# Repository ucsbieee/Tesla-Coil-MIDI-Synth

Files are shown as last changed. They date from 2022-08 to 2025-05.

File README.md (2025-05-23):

# UCSB IEEE Tesla Coil MIDI Synthesizer

This is the firmware and design files for a device to convert MIDI data to pulses to drive a Tesla coil. It enumerates as a USB MIDI device and can be sent live play data or a recorded MIDI file. It also enumerates as a USB audio device and can be sent PCM audio for greater control or for live instrument use.

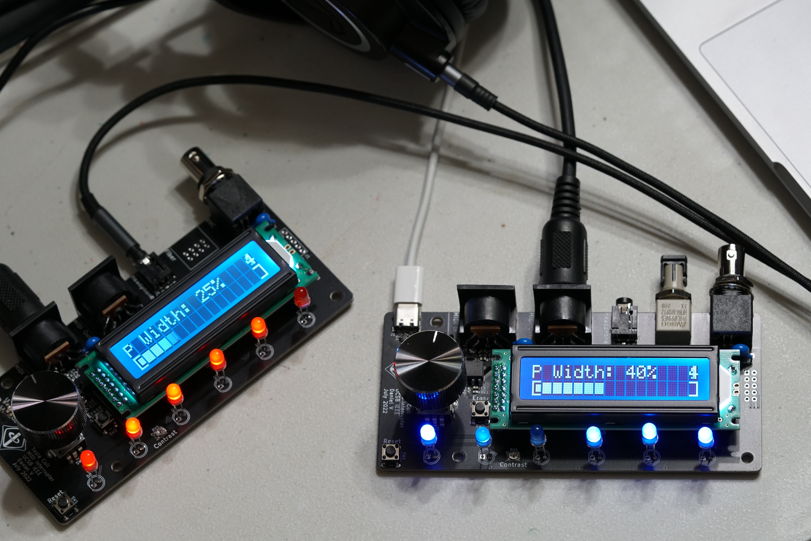
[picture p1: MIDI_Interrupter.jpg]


The circuit board is based off of the [Arduino Due](https://docs.arduino.cc/hardware/due). It uses the similar SAM3A4C MCU, and has a fiber optic output for the big DRSSTC and a BNC port for the small Tesla Coil. It also has isolated physical MIDI in/out ports for connecting other instruments or daisy-chaining more MIDI interrupters. See [ucsbieee/ArduinoCore-SAM3A4C](https://github.com/ucsbieee/ArduinoCore-SAM3A4C) for an Arduino IDE board definition.

The device has six voices, which can each produce a single square wave tone at a variable duty cycle. They are ORed together to give a polyphonic effect.

## Uploading Firmware

New firmware can be uploaded using the Arduino IDE and the aforementioned [board definition](https://github.com/ucsbieee/ArduinoCore-SAM3A4C), or the [latest release](https://github.com/ucsbieee/Tesla-Coil-MIDI-Synth/releases/latest) (`.bin` file) can be uploaded using [BOSSA](https://github.com/shumatech/BOSSA) ([available from Homebrew](https://formulae.brew.sh/formula/bossa)).

### Arduino Library Dependencies
Available from the Arduino IDE library manager
 * [MIDIUSB](https://github.com/arduino-libraries/MIDIUSB)
 * [DueFlashStorage](https://github.com/sebnil/DueFlashStorage) (only if `SAVE_BASE_MIDI` is enabled, which it is not by default)

## Emulator

There is also an emulator that can be compiled to run on a normal computer so that songs can be developed without the physical hardware.

## MIDI Information

### MIDI Channels
 1. Clean (no effects)
 2. Effects
 3. Arpeggio and effects
 4. Drums

Standard MIDI pitch bend and aftertouch messages apply to all channels.

### Effects (CC number in parentheses)
 * Tremolo (rate = 102, depth = 92, delay = 103)
 * Vibrato (rate = 76, depth = 77, delay = 78)
 * ADSR (116, 117, 118, 119)
 * Arpeggio rate (14)

### Drum Samples
 * Kick (36/C2)
 * Snare (40/E2)
 * Clap (39/D#2)
 * Tom (48/C3)
 * Closed hi-hat (42/F#2)

### Physical MIDI Ports
All MIDI messages that come in over USB or the MIDI IN port are sent out the MIDI OUT port. Additionally, all messages that come in over the MIDI IN port are sent back to the computer over USB. This allows daisy-chaining multiple controllers using the physical MIDI ports, and allows recording any inputs from the physical MIDI IN port to the computer. Be careful not to create infinite MIDI loops in your DAW because of these behaviors.

## Audio Processing Modes
 * **Predictive**: Predict how much energy will be in a pulse based on the filtered derivative near zero crossing.
 * **Pulse Energy**: Output a pulse after a delay (~5ms) with width proportional to the area of the input pulse above the noise gate level. Pulse width clamped to maximum setting.
 * **Schmitt**: Output on when audio exceeds the noise gate level, then only turn off again once audio falls below negative noise gate level (Schmitt trigger behavior). Pulse width clamped to maximum setting.
 * **Clamped Binary**: Output on when audio exceeds the noise gate level. Pulse width clamped to maximum setting.
 * **Binary**: Output on when audio exceeds the noise gate level.
 * **Binary DDT**: Output on when the derivative of the audio exceeds a certain threshold. Pulse width clamped to maximum setting.
 * **Bin Oct Down**: Toggle output on rising edge. Input schmitt triggered. Output pulse width limited.
 * **PWM**: Output 48kHz PWM with pulse width proportional to the sample value. Audio baseline level subtracted away.
 * **PWM DDT**: Output 48kHz PWM with pulse width proportional to the derivative of the audio.

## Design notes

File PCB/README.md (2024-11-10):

# PCB

## Audio

We had the idea of using sampled audio output after the V2 boards were made. Unfortunately, the (unused) pins that have the necessary DMA capability are not broken out on the board. So, to get audio capability, you will need to solder a very thin wire (~34AWG) underneath the D10 pad on the microcontroller and run it to EXT_IN on the expansion header. Hope you're comfortable with BGA soldering :)

## Hacking
There are twelve extra pins on the board marked "Expansion," and they're there so you can add extra inputs or whatever you want to the board. Three are power (5V, 3.3V, GND), and seven go to digital/ADC pins on the MCU. The Arduino board definition is based off of the DUE, so take a look at the [DUE schematic](https://www.arduino.cc/en/uploads/Main/arduino-Due-schematic.pdf) or [variant.cpp](https://github.com/ucsbieee/ArduinoCore-SAM3A4C/blob/master/variants/arduino_due_x/variant.cpp) to see which Arduino pins they map to. These could be good for adding physical controls/music input of some kind.

There's also an input that is ORed with the voice signals before being sent to the outputs, and a 3.3V logic level copy of that combined output signal available. You can use these to make use of the output circuitry to control the Tesla coil with your own signals, combine voices from multiple interrupter boards (chaos), or whatever else you can think of.

## Erase and Reset Buttons
Pressing the "Erase" button on the PCB immediately deletes the firmware. Don't push it unless you intend to. This microcontroller has the SAM-BA bootloader included in ROM which is activated when the chip is blank, causing it to enumerate as a USB serial device and accept new firmware. If you ever get the board into a state where you can't program it, hit the erase button then reset and that should fix it. After uploading new firmware to a blank chip, you may need to re-power (instead of reset) the board. If it wasn't blank, you usually can just hit the reset button to make it run the new firmware.

If you accidentally nuked the chip, there's a firmware binary file in this repo and you can upload it using [bossa](https://github.com/shumatech/BOSSA/releases).

## If you want to make more

There should be a few extra unpopulated boards in the lab somewhere. See [BOM.csv](https://github.com/ucsbieee/Tesla-Coil-MIDI-Synth/blob/master/PCB/BOM.csv) for a list of parts you'll need. Parts without a DigiKey part number are generic stuff. Most resistors and caps are 0603, with a few 0805 (see footprint column).

You'll also likely want to use a solder paste stencil, especially for the BGA microcontroller. A file for the stencil is in the Gerber folder.

If you guys ever build a Tesla Coil symphony with a bunch of these things, please invite me back, I want to see :)

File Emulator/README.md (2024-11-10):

# Emulated MIDI Synth

This folder contains code to patch/modify the software that runs on the microcontroller on the Tesla coil controller box so that it can run on a normal computer. There is also some glue code that uses [PortAudio](https://github.com/PortAudio/portaudio) and [libremidi](https://github.com/jcelerier/libremidi) to enable MIDI input and sound output. This allows songs to be more easily developed without needing a physical controller box plugged in (especially if you want to use the CC-controlled effects channels).

## Building

Prerequisites
 * [`portaudiocpp`](https://github.com/PortAudio/portaudio)
 * [`fftw`](https://www.fftw.org)
 * [`libremidi`](https://github.com/jcelerier/libremidi)
 * [`SDL2`](https://www.libsdl.org) (and `SDL2_ttf`)
 * GNU `make`
 * `patch`
 * C++17 compiler

You may need to modify the makefile slightly to get it to find the libraries on your system (it uses `pkg-config` by default) or to select a different backend for `libremidi` depending on your operating system.

Running `make` will take the code from the main firmware in this repo and apply some patches to remove MCU-specific code.

## Using

When the program is run, it will ask you for audio input and output devices and a MIDI input device. Set the audio input device to a guitar or loopback source, output device to your headphones, and the MIDI input to a loopback device coming out of your DAW. It should respond exactly like the real MIDI controller since it's the exact same code. The sound is approximated using an FIR filter.

If run with the `--stereo` flag, the program will emulate two Tesla coil controllers, one panned to the left and the other to the right. The right one responds to MIDI channels starting at 5 instead of 1.

Use the arrow keys and return/space or mouse wheel and click to navigate the settings.

## Modifying

Significant modifications to the MCU firmware may require the patches to be re-done. Changes to files can be propagated back to the `.patch` files by running `make patches` after modifying the files produced by running `make build/patched/x.cpp`.

## Attribution

LCD font from [here](https://fontstruct.com/fontstructions/show/476121/lcd_dot_matrix_hd44780u).

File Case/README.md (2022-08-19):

# Case
* [Case screws](https://www.mcmaster.com/94629A680/)
* [MIDI port screws](https://www.mcmaster.com/90380A005/)

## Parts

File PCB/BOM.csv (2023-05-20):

Item | Qty | Reference(s) | Value | LibPart | Footprint | Datasheet | DigiKey Part Number
1 | 5 | C1, C5, C10, C17, C24 | 10µ | Device:C_Small | Capacitor_SMD:C_0805_2012Metric_Pad1.18x1.45mm_HandSolder
2 | 16 | C2, C3, C4, C6, C7, C8, C11, C14, C15, C16, C18, C20, C21, C22, C25, C26 | 100n | Device:C_Small | Capacitor_SMD:C_0603_1608Metric_Pad1.08x0.95mm_HandSolder
3 | 3 | C9, C12, C13 | 10p | Device:C_Small | Capacitor_SMD:C_0603_1608Metric_Pad1.08x0.95mm_HandSolder
4 | 2 | C19, C23 | 1n | Device:C_Small | Capacitor_THT:C_Disc_D7.5mm_W5.0mm_P7.50mm
5 | 1 | D1 | D1213 | Custom_Symbols:D1213 | Custom_Footprints:SOT25 | https://www.diodes.com/assets/Datasheets/D1213A-02SM.pdf | D1213A-02SM-7DICT-ND
6 | 1 | D2 | Voice 1 | Device:LED | LED_THT:LED_D5.0mm
7 | 1 | D3 | Voice 2 | Device:LED | LED_THT:LED_D5.0mm
8 | 1 | D4 | Voice 3 | Device:LED | LED_THT:LED_D5.0mm
9 | 1 | D5 | Voice 4 | Device:LED | LED_THT:LED_D5.0mm
10 | 1 | D6 | Voice 5 | Device:LED | LED_THT:LED_D5.0mm
11 | 1 | D7 | Voice 6 | Device:LED | LED_THT:LED_D5.0mm
12 | 1 | D8 | D | Device:D | Diode_SMD:D_SOD-123 |  | 1727-7320-1-ND
13 | 6 | FB1, FB2, FB3, FB4, FB5, FB6 | FerriteBead_Small | Device:FerriteBead_Small | Inductor_SMD:L_0805_2012Metric_Pad1.05x1.20mm_HandSolder |  | 1276-6377-1-ND
14 | 1 | FL1 | Filter_EMI_CommonMode | Device:Filter_EMI_CommonMode | Custom_Footprints:Bourns_SRF2012AA |  | SRF2012A-900YACT-ND
15 | 1 | J1 | USB C | Connector:USB_C_Receptacle_USB2.0 | Custom_Footprints:GCT_USBC_USB4105 |  | 2073-USB4105-GF-ACT-ND
16 | 1 | J2 | JTAG | Connector_Generic:Conn_02x05_Odd_Even | Connector_PinHeader_1.27mm:PinHeader_2x05_P1.27mm_Vertical
17 | 1 | J3 | Expansion | Connector_Generic:Conn_02x05_Odd_Even | Connector_PinHeader_2.54mm:PinHeader_2x05_P2.54mm_Vertical
18 | 1 | J4 | Headphone Output | Connector:AudioJack3_SwitchTR | Custom_Footprints:Adam_Tech_ASJ-99H-X-HT-TR |  | 2057-ASJ-99H-R-HT-T/RCT-ND
19 | 1 | J5 | BNC Output | Connector:Conn_Coaxial | Custom_Footprints:Adam_Tech_BNC_RF1-01K-D-00-50-BK-HDW |  | 2057-RF1-01K-D-00-50-BK-HDW-ND, SC2808-ND
20 | 1 | J6 | MIDI Out | Connector:DIN-5_180degree | Custom_Footprints:CUI_DIN_SDS-50J |  | CP-2350-ND
21 | 1 | J7 | MIDI In | Connector:DIN-5_180degree | Custom_Footprints:CUI_DIN_SDS-50J |  | CP-2350-ND
22 | 1 | L1 | 4.7µ | Device:L | Inductor_SMD:L_0805_2012Metric_Pad1.05x1.20mm_HandSolder |  | 445-8659-1-ND
23 | 10 | R1, R2, R4, R7, R8, R9, R17, R20, R22, R27 | 10k | Device:R_US | Resistor_SMD:R_0603_1608Metric_Pad0.98x0.95mm_HandSolder
24 | 1 | R3 | 6.8k | Device:R_US | Resistor_SMD:R_0603_1608Metric_Pad0.98x0.95mm_HandSolder
25 | 2 | R5, R6 | 39 | Device:R_US | Resistor_SMD:R_0603_1608Metric_Pad0.98x0.95mm_HandSolder
26 | 11 | R10, R11, R12, R13, R14, R15, R21, R23, R24, R25, R26 | 220 | Device:R_US | Resistor_SMD:R_0603_1608Metric_Pad0.98x0.95mm_HandSolder
27 | 2 | R16, R28 | 5.1k | Device:R_US | Resistor_SMD:R_0603_1608Metric_Pad0.98x0.95mm_HandSolder
28 | 2 | R18, R19 | 100 | Device:R_US | Resistor_SMD:R_0603_1608Metric_Pad0.98x0.95mm_HandSolder
29 | 1 | R29 | 3.3 | Device:R_US | Resistor_SMD:R_0603_1608Metric_Pad0.98x0.95mm_HandSolder
30 | 1 | RV1 | Contrast | Device:R_Potentiometer_Trim_US | Potentiometer_SMD:Potentiometer_Bourns_TC33X_Vertical |  | TC33X-103ECT-ND
31 | 2 | SG1, SG2 | SparkGap | Device:SparkGap | Custom_Footprints:Spark_Gap
32 | 1 | SW1 | Reset | Switch:SW_Push | Button_Switch_THT:SW_PUSH_6mm
33 | 1 | SW2 | Erase | Switch:SW_Push | Button_Switch_THT:SW_PUSH_6mm
34 | 1 | SW3 | Rotary Encoder | Device:RotaryEncoder_Switch | Custom_Footprints:Bourns_Encoder_PEC12R-4130F-S0012 |  | PEC12R-4130F-S0012-ND, 1568-1601-ND
35 | 1 | U1 | AZ1117-3.3 | Regulator_Linear:AZ1117-3.3 | Package_TO_SOT_SMD:SOT-89-3 |  | AZ1117CR-3.3TRG1DICT-ND
36 | 1 | U2 | SAM3A4C | Custom_Symbols:SAM3A4C | Package_BGA:TFBGA-100_9.0x9.0mm_Layout10x10_P0.8mm | http://www.microchip.com/mymicrochip/filehandler.aspx?ddocname=en590017 | 1611-ATSAM3A4CA-CU-ND
37 | 1 | U3 | SFH617A-1 | Isolator:SFH617A-1 | Package_DIP:DIP-4_W10.16mm |  | 732-140817141310-ND
38 | 1 | U4 | HFBR-1412PTZ | Custom_Symbols:HFBR-1412PTZ | Custom_Footprints:Broadcom_HFBR-1412PTZ | https://docs.broadcom.com/doc/AV02-0176EN | 516-4074-ND
39 | 1 | U5 | 74LVC4245A | Custom_Symbols:74LVC4245A | Package_SO:TSSOP-24_4.4x7.8mm_P0.65mm | https://assets.nexperia.com/documents/data-sheet/74LVC4245A.pdf | 1727-4308-1-ND
40 | 1 | U6 | 6N137 | Isolator:6N137 | Package_DIP:DIP-8_W7.62mm |  | 160-1791-ND
41 | 1 | U7 | ERM1602 | Custom_Symbols:ERM1602 | Custom_Footprints:ERM1602 | https://www.buydisplay.com/download/manual/ERM1602-2.1_Series_Datasheet.pdf
42 | 1 | U8 | 4075 | 4xxx:4075 | Package_SO:SOIC-14_3.9x8.7mm_P1.27mm |  | 296-SN74HCS4075DRCT-ND
43 | 1 | U9 | 74LVC1G17 | 74xGxx:74LVC1G17 | Package_TO_SOT_SMD:SOT-23-5 |  | 296-11933-1-ND
44 | 1 | Y1 | 12MHz | Device:Crystal_GND24 | Crystal:Crystal_SMD_Abracon_ABM8G-4Pin_3.2x2.5mm |  | 535-10901-1-ND

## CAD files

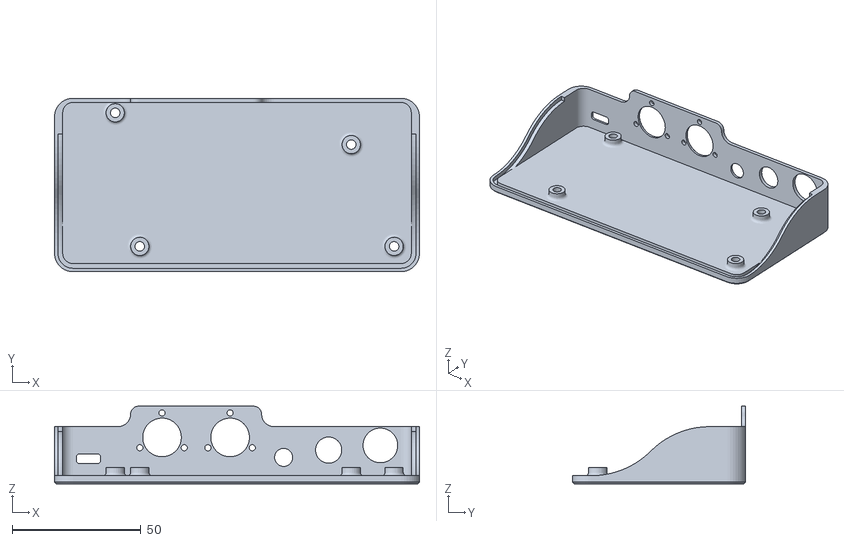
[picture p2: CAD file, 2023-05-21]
Case/Bottom.stl
141.6 x 67.3 x 30.2

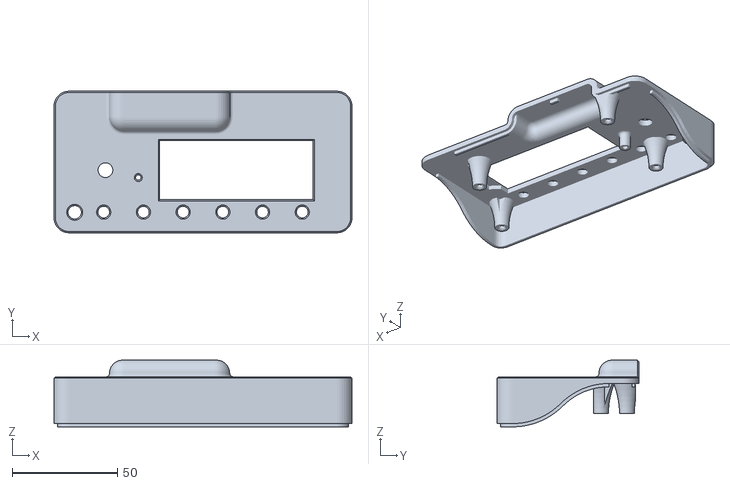
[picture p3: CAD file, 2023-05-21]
Case/Top.stl
141.6 x 67.3 x 31.8

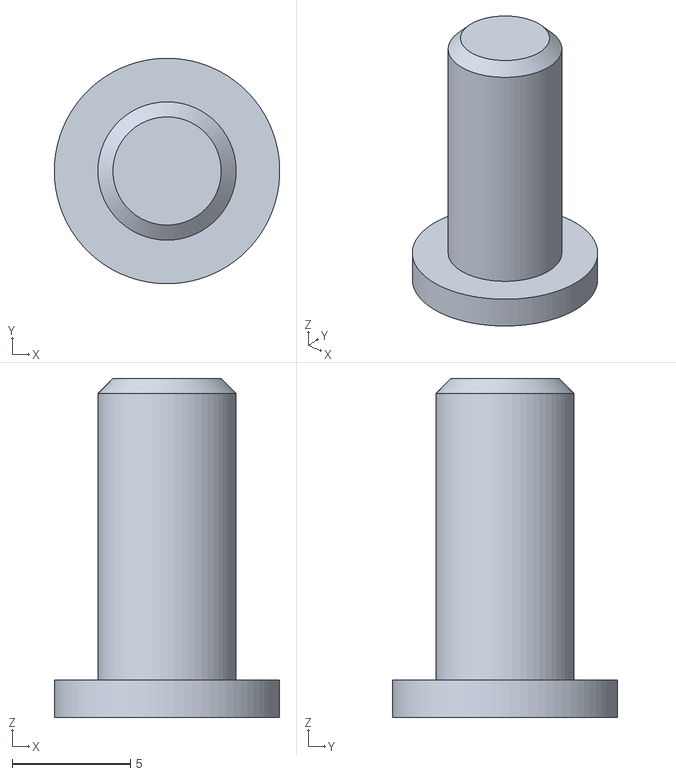
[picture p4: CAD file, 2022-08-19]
Case/Button Pusher.stl
9.52 x 9.52 x 14.3

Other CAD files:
Case/Bottom No Fiber Optic.stl

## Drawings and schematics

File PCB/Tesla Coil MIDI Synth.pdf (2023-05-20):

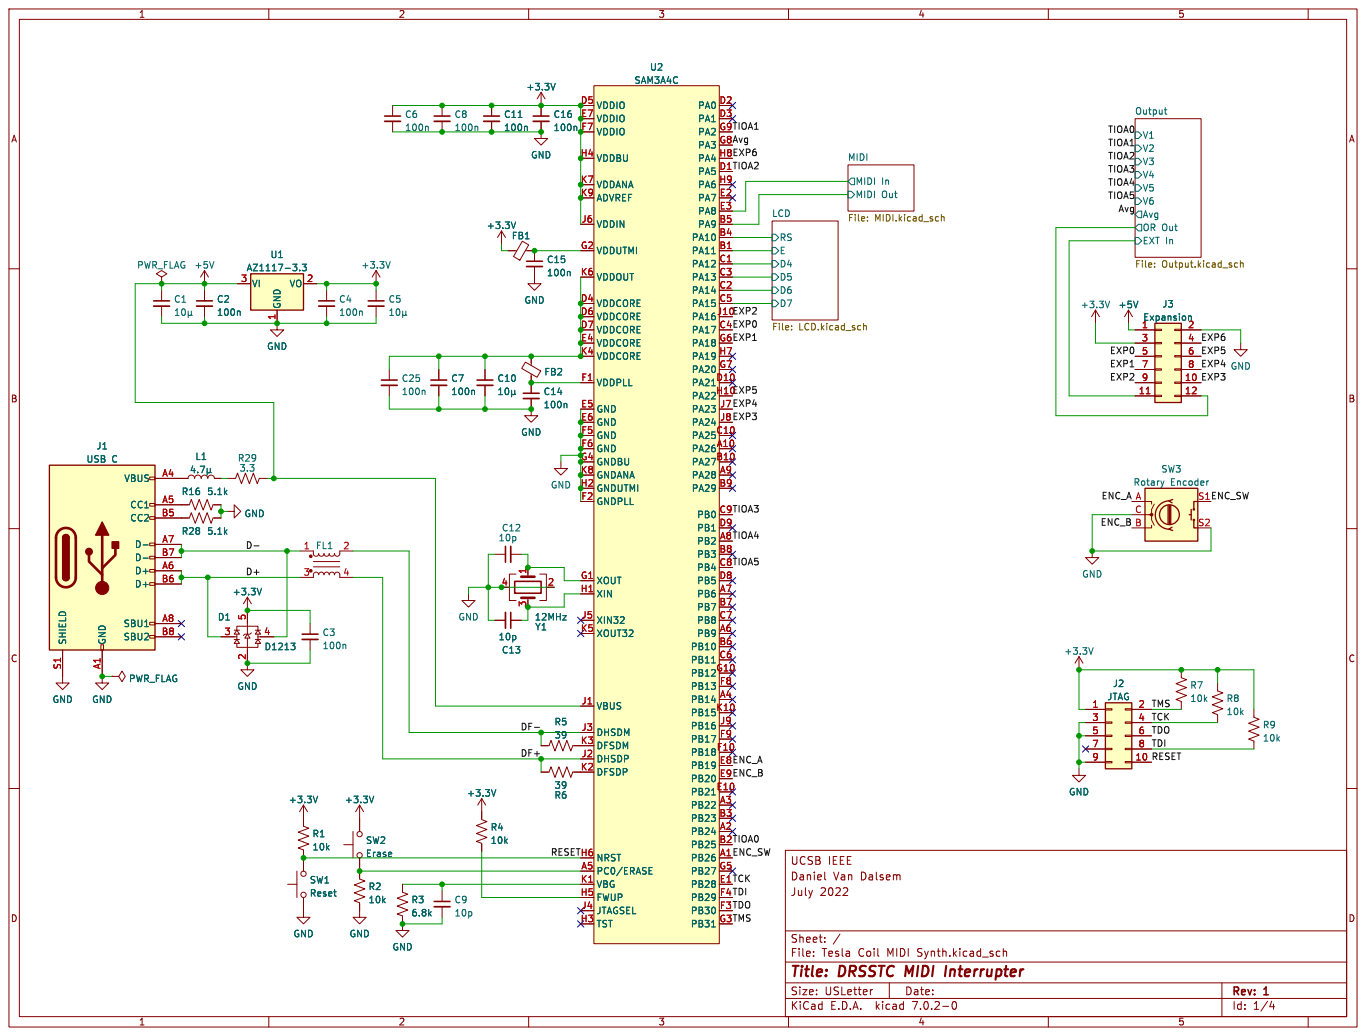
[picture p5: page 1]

PA7 E2 PA8 E3 VDDCORE E4 GND E5 GND E6 VDDIO E7
File: LCD.kicad_schMIDI In MIDI Out MIDI File: MIDI.kicad_sch C16
100n GND

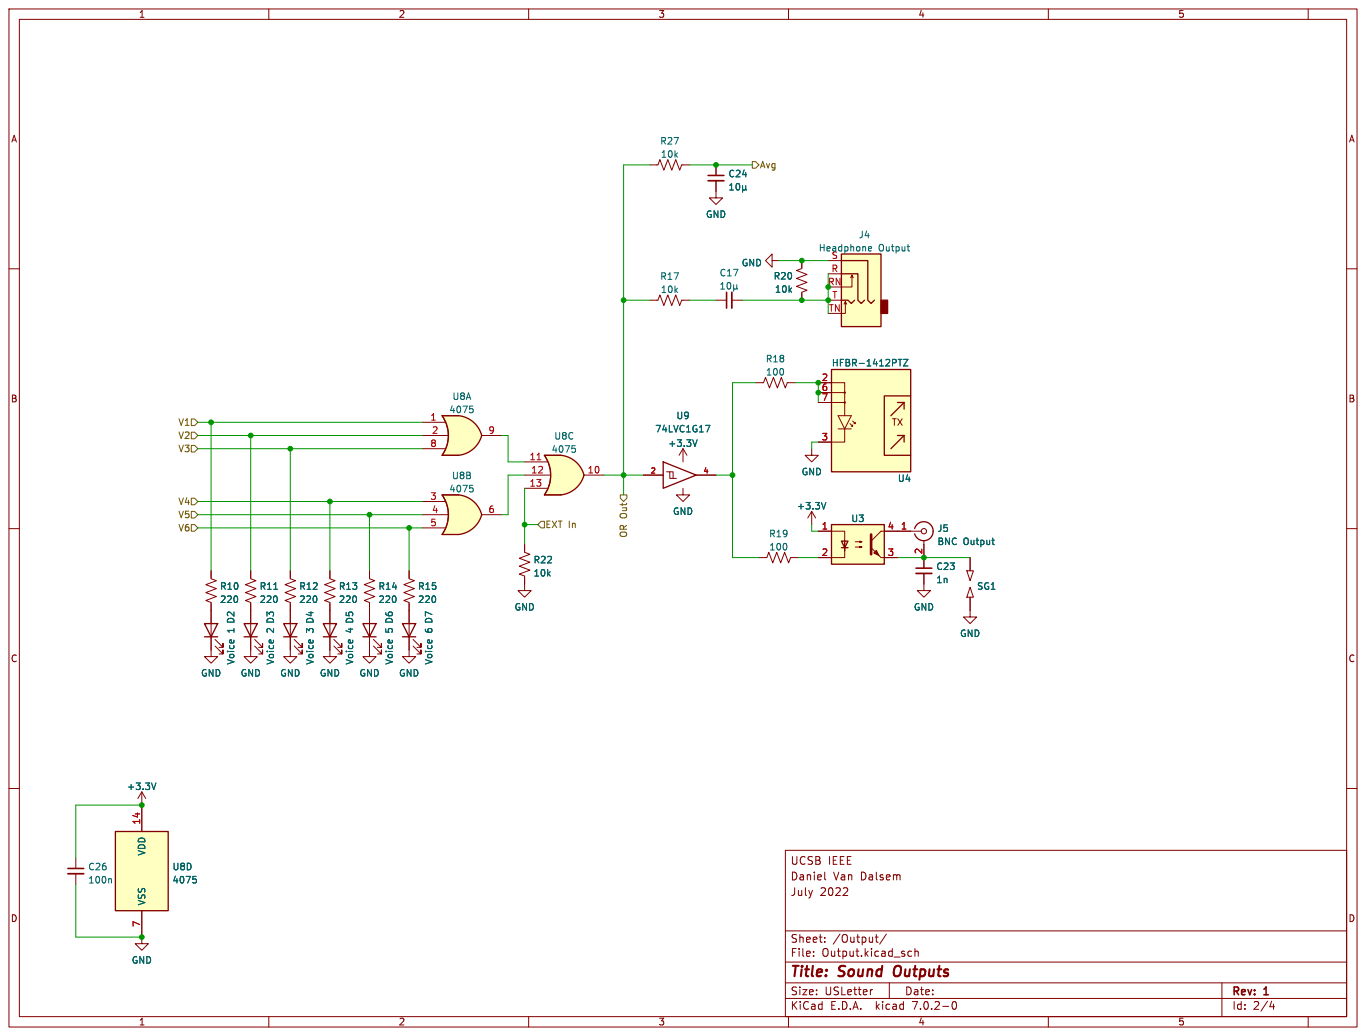
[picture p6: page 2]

7 GND GND D2 Voice 1 GND D3 Voice 2 GND

File: Output.kicad_sch Sheet: /Output/
Id: 2/4 Title: Sound Outputs

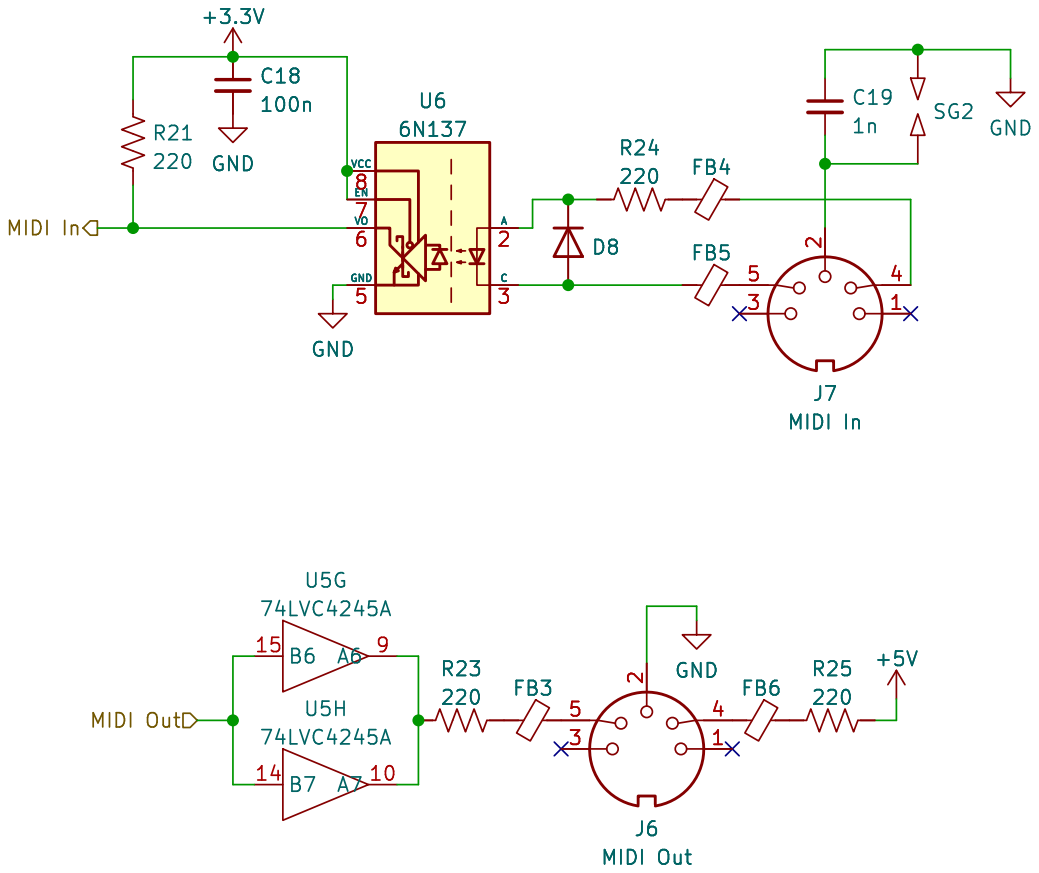
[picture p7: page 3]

Id: 3/4 Title: MIDI Interface

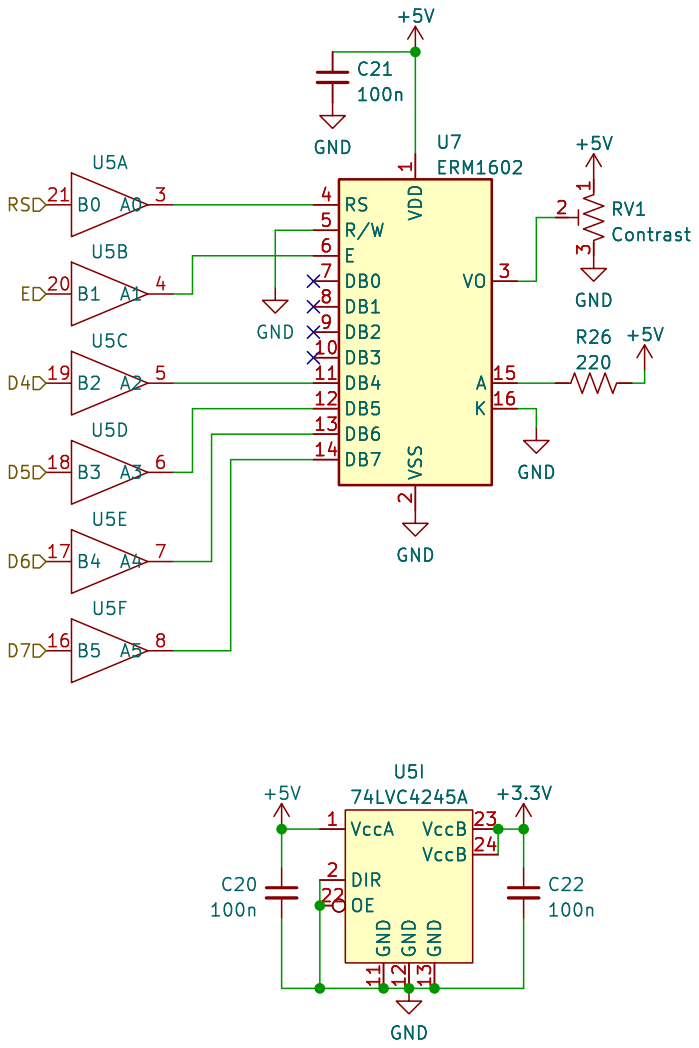
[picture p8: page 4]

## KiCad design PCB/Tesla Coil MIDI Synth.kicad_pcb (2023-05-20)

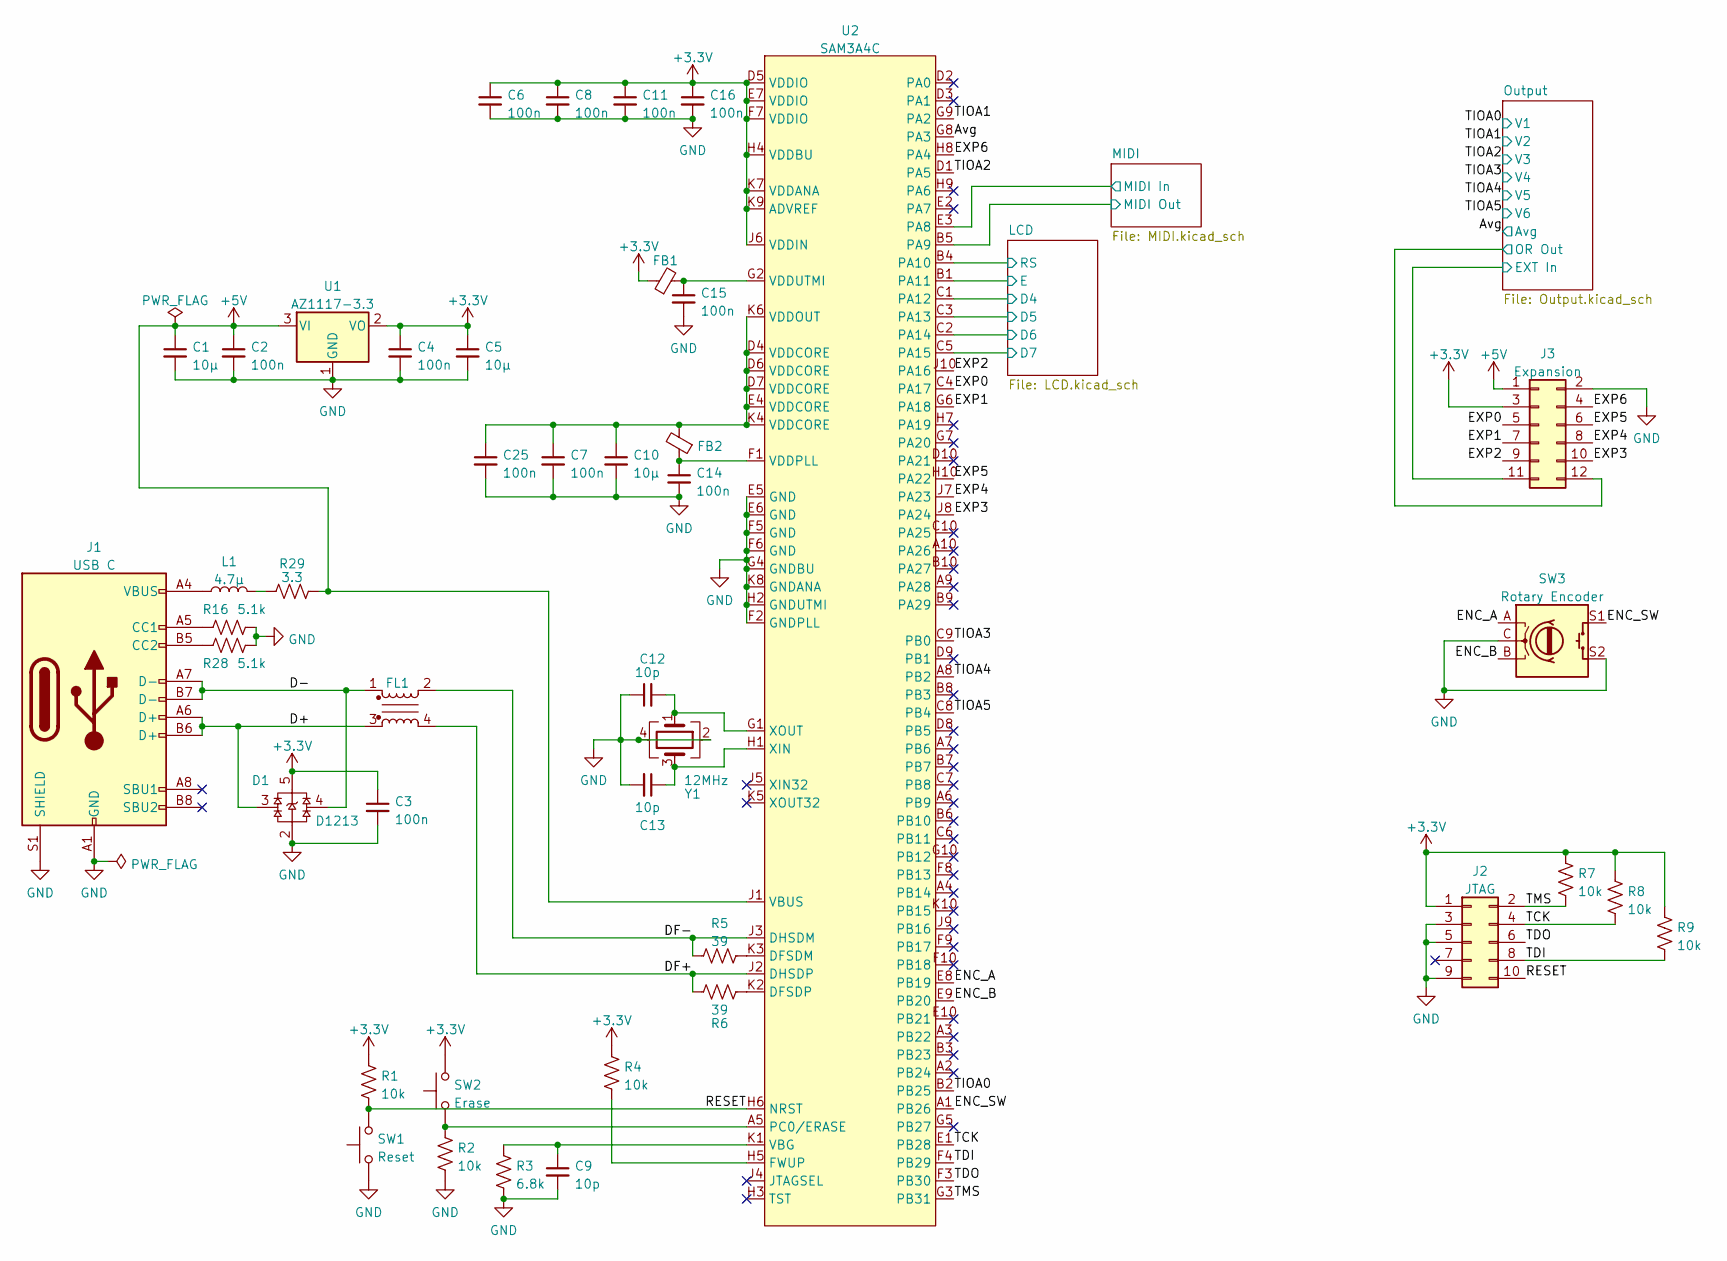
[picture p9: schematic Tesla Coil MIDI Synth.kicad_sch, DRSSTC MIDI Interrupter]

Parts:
C1, C5, C10: 10µ; C_0805_2012Metric_Pad1.18x1.45mm_HandSolder
C2, C3, C4, C6, C7, C8, C11, C14, C15, C16, C25: 100n; C_0603_1608Metric_Pad1.08x0.95mm_HandSolder
C9, C12, C13: 10p; C_0603_1608Metric_Pad1.08x0.95mm_HandSolder
D1: D1213; SOT25
FB1, FB2: FerriteBead_Small; L_0805_2012Metric_Pad1.05x1.20mm_HandSolder
FL1: Filter_EMI_CommonMode; Bourns_SRF2012AA
J1: USB C; GCT_USBC_USB4105
J2: JTAG; PinHeader_2x05_P1.27mm_Vertical
J3: Expansion; PinHeader_2x06_P2.54mm_Vertical
L1: 4.7µ; L_0805_2012Metric_Pad1.05x1.20mm_HandSolder
R1, R2, R4, R7, R8, R9: 10k; R_0603_1608Metric_Pad0.98x0.95mm_HandSolder
R3: 6.8k; R_0603_1608Metric_Pad0.98x0.95mm_HandSolder
R5, R6: 39; R_0603_1608Metric_Pad0.98x0.95mm_HandSolder
R16, R28: 5.1k; R_0603_1608Metric_Pad0.98x0.95mm_HandSolder
R29: 3.3; R_0603_1608Metric_Pad0.98x0.95mm_HandSolder
SW1: Reset; SW_PUSH_6mm
SW2: Erase; SW_PUSH_6mm
SW3: Rotary Encoder; Bourns_Encoder_PEC12R-4130F-S0012
U1: AZ1117-3.3; SOT-89-3
U2: SAM3A4C; TFBGA-100_9.0x9.0mm_Layout10x10_P0.8mm
Y1: 12MHz; Crystal_SMD_Abracon_ABM8G-4Pin_3.2x2.5mm

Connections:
+3.3V: C3.1, C4.1, C5.1, C6.1, C8.1, C11.1, C16.1, D1.5, FB1.1, J2.1, J3.3, R1.1, R4.1, R7.1, R8.1, R9.1, SW2.2, U1.2 (VO), U2.D5 (VDDIO), U2.E7 (VDDIO), U2.F7 (VDDIO), U2.H4 (VDDBU), U2.J6 (VDDIN), U2.K7 (VDDANA), U2.K9 (ADVREF); also elsewhere on the board
+5V: C1.1, C2.1, J3.1, R29.2, U1.3 (VI), U2.J1 (VBUS); also elsewhere on the board
/Avg: U2.G8 (PA3); also elsewhere on the board
/D+: D1.3, FL1.3, J1.A6 (D+), J1.B6 (D+)
/D-: D1.4, FL1.1, J1.A7 (D-), J1.B7 (D-)
/DF+: FL1.4, R6.1, U2.J2 (DHSDP)
/DF-: FL1.2, R5.1, U2.J3 (DHSDM)
/ENC_A: SW3.A, U2.E8 (PB19)
/ENC_B: SW3.B, U2.E9 (PB20)
/ENC_SW: SW3.S1, U2.A1 (PB26)
/EXP0: J3.5, U2.C4 (PA17)
/EXP1: J3.7, U2.G6 (PA18)
/EXP2: J3.9, U2.J10 (PA16)
/EXP3: J3.10, U2.J8 (PA24)
/EXP4: J3.8, U2.J7 (PA23)
/EXP5: J3.6, U2.H10 (PA22)
/EXP6: J3.4, U2.H8 (PA4)
/LCD/D4: U2.C1 (PA12); also elsewhere on the board
/LCD/D5: U2.C3 (PA13); also elsewhere on the board
/LCD/D6: U2.C2 (PA14); also elsewhere on the board
/LCD/D7: U2.C5 (PA15); also elsewhere on the board
/LCD/E: U2.B1 (PA11); also elsewhere on the board
/LCD/RS: U2.B4 (PA10); also elsewhere on the board
/MIDI/MIDI In: U2.E3 (PA8); also elsewhere on the board
/MIDI/MIDI Out: U2.B5 (PA9); also elsewhere on the board
/Output/EXT In: J3.11; also elsewhere on the board
/Output/OR Out: J3.12; also elsewhere on the board
/RESET: J2.10, R1.2, SW1.2, U2.H6 (NRST)
/TCK: J2.4, R8.2, U2.E1 (PB28)
/TDI: J2.8, R9.2, U2.F4 (PB29)
/TDO: J2.6, U2.F3 (PB30)
/TIOA0: U2.B2 (PB25); also elsewhere on the board
/TIOA1: U2.G9 (PA2); also elsewhere on the board
/TIOA2: U2.D1 (PA5); also elsewhere on the board
/TIOA3: U2.C9 (PB0); also elsewhere on the board
/TIOA4: U2.A8 (PB2); also elsewhere on the board
/TIOA5: U2.C8 (PB4); also elsewhere on the board
/TMS: J2.2, R7.2, U2.G3 (PB31)
GND: C1.2, C2.2, C3.2, C4.2, C5.2, C6.2, C7.2, C8.2, C9.2, C10.2, C11.2, C12.1, C13.2, C14.2, C15.2, C16.2, C25.2, D1.2, J1.A1 (GND), J1.A12 (GND), J1.B1 (GND), J1.B12 (GND), J1.S1 (SHIELD), J2.3, J2.5, J2.9, J3.2, R2.2, R3.2, R16.2, R28.2, SW1.1, SW3.C, SW3.S2, U1.1 (GND), U2.E5 (GND), U2.E6 (GND), U2.F2 (GNDPLL), U2.F5 (GND), U2.F6 (GND), U2.G4 (GNDBU), U2.H2 (GNDUTMI), U2.K8 (GNDANA), Y1.2, Y1.4; also elsewhere on the board
unnamed: J1.A5 (CC1), R16.1
unnamed: J1.B5 (CC2), R28.1
unnamed: J1.A4 (VBUS), J1.A9 (VBUS), J1.B4 (VBUS), J1.B9 (VBUS), L1.1
unnamed: L1.2, R29.1
unnamed: R5.2, U2.K3 (DFSDM)
unnamed: R6.2, U2.K2 (DFSDP)
unnamed: R4.2, U2.H5 (FWUP)
unnamed: R2.1, SW2.1, U2.A5 (PC0/ERASE)
unnamed: C9.1, R3.1, U2.K1 (VBG)
unnamed: C7.1, C10.1, C25.1, FB2.2, U2.D4 (VDDCORE), U2.D6 (VDDCORE), U2.D7 (VDDCORE), U2.E4 (VDDCORE), U2.K4 (VDDCORE), U2.K6 (VDDOUT)
unnamed: C14.1, FB2.1, U2.F1 (VDDPLL)
unnamed: C15.1, FB1.2, U2.G2 (VDDUTMI)
unnamed: C13.1, U2.H1 (XIN), Y1.3
unnamed: C12.2, U2.G1 (XOUT), Y1.1

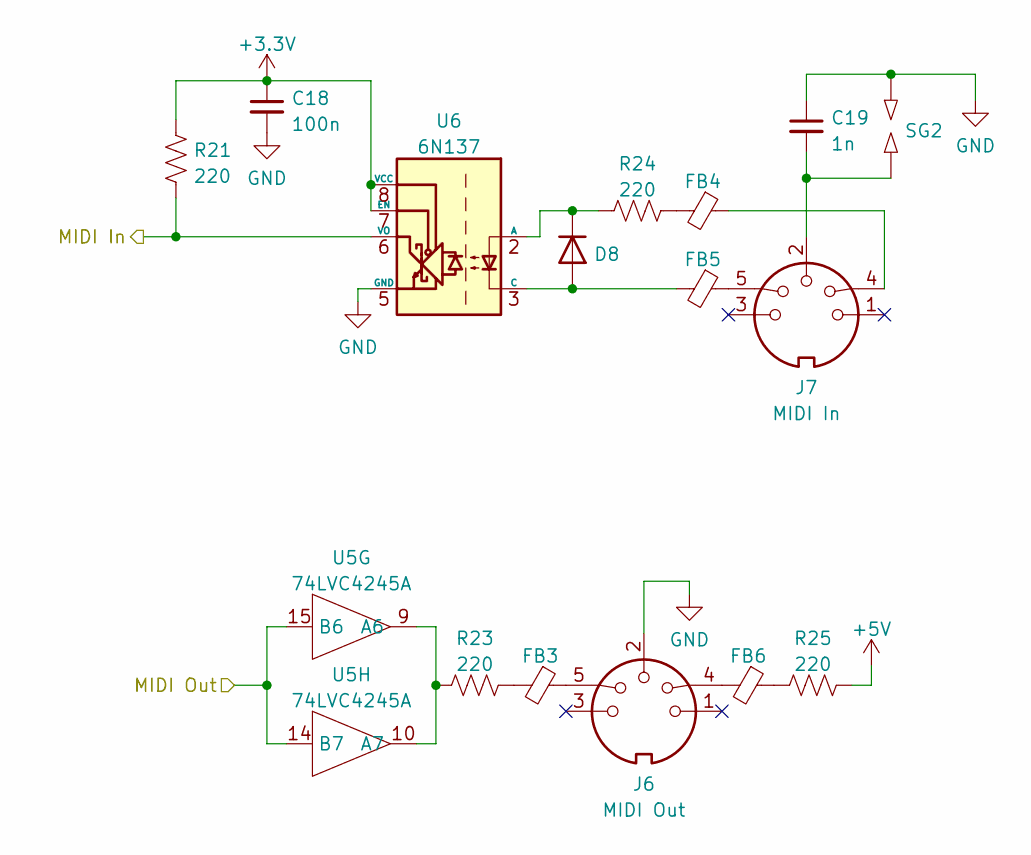
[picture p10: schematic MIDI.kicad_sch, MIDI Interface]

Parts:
C18: 100n; C_0603_1608Metric_Pad1.08x0.95mm_HandSolder
C19: 1n; C_Disc_D7.5mm_W5.0mm_P7.50mm
D8: D; D_SOD-123
FB3, FB4, FB5, FB6: FerriteBead_Small; L_0805_2012Metric_Pad1.05x1.20mm_HandSolder
J6: MIDI Out; CUI_DIN_SDS-50J
J7: MIDI In; CUI_DIN_SDS-50J
R21, R23, R24, R25: 220; R_0603_1608Metric_Pad0.98x0.95mm_HandSolder
SG2: SparkGap; Spark_Gap
U5: 74LVC4245A; TSSOP-24_4.4x7.8mm_P0.65mm
U6: 6N137; DIP-8_W7.62mm

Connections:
+3.3V: C18.1, R21.1, U6.7 (EN), U6.8 (VCC); also elsewhere on the board
+5V: R25.2; also elsewhere on the board
/MIDI/MIDI In: R21.2, U6.6 (VO); also elsewhere on the board
/MIDI/MIDI Out: U5.14 (B7), U5.15 (B6); also elsewhere on the board
GND: C18.2, C19.1, J6.2, SG2.2, U6.5 (GND); also elsewhere on the board
unnamed: C19.2, J7.2, SG2.1
unnamed: D8.2 (A), FB5.2, U6.3 (C)
unnamed: D8.1 (K), R24.1, U6.2 (A)
unnamed: FB3.1, J6.5
unnamed: FB3.2, R23.2
unnamed: FB4.1, J7.4
unnamed: FB4.2, R24.2
unnamed: FB5.1, J7.5
unnamed: FB6.1, R25.1
unnamed: FB6.2, J6.4
unnamed: R23.1, U5.9 (A6), U5.10 (A7)

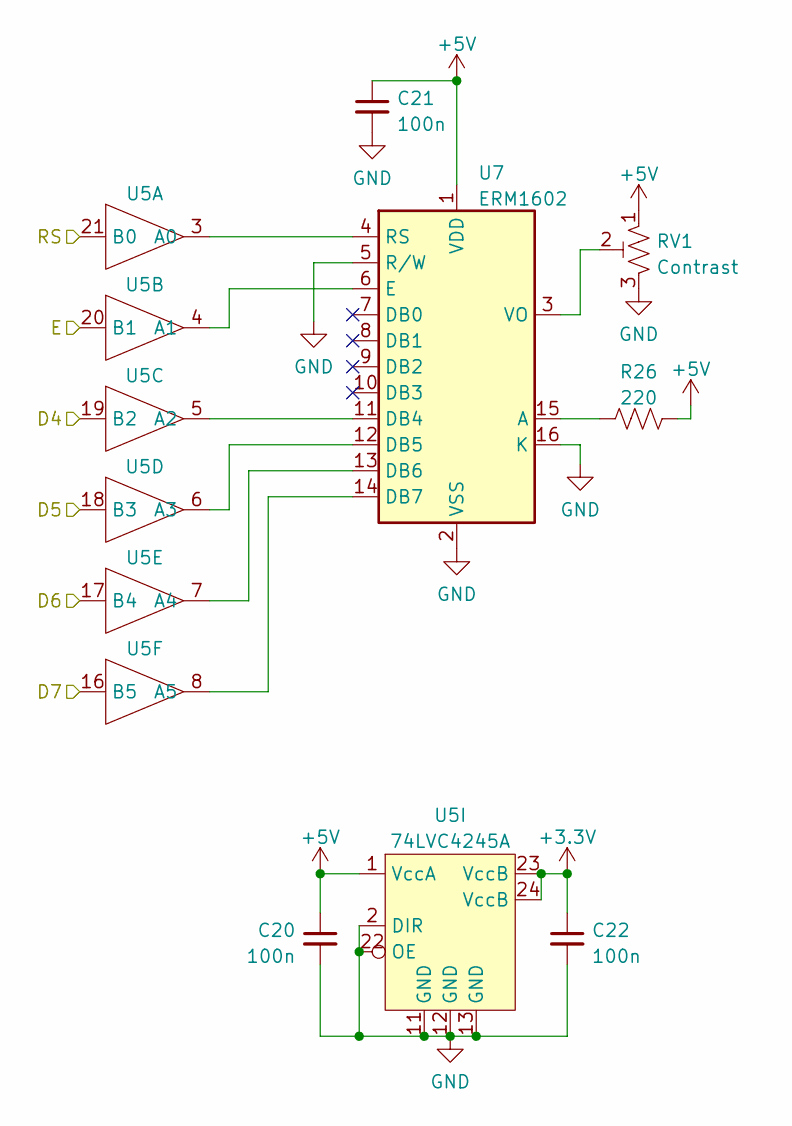
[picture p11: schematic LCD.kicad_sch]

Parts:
C20, C21, C22: 100n; C_0603_1608Metric_Pad1.08x0.95mm_HandSolder
R26: 220; R_0603_1608Metric_Pad0.98x0.95mm_HandSolder
RV1: Contrast; Potentiometer_Bourns_TC33X_Vertical
U5: 74LVC4245A; TSSOP-24_4.4x7.8mm_P0.65mm
U7: ERM1602

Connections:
+3.3V: C22.1, U5.23 (VccB), U5.24 (VccB); also elsewhere on the board
+5V: C20.1, C21.1, R26.2, RV1.1, U5.1 (VccA), U7.1 (VDD); also elsewhere on the board
/LCD/D4: U5.19 (B2); also elsewhere on the board
/LCD/D5: U5.18 (B3); also elsewhere on the board
/LCD/D6: U5.17 (B4); also elsewhere on the board
/LCD/D7: U5.16 (B5); also elsewhere on the board
/LCD/E: U5.20 (B1); also elsewhere on the board
/LCD/RS: U5.21 (B0); also elsewhere on the board
GND: C20.2, C21.2, C22.2, RV1.3, U5.2 (DIR), U5.11 (GND), U5.12 (GND), U5.13 (GND), U5.22 (OE), U7.2 (VSS), U7.5 (R/W), U7.16 (K); also elsewhere on the board
unnamed: U5.3 (A0), U7.4 (RS)
unnamed: U5.4 (A1), U7.6 (E)
unnamed: U5.5 (A2), U7.11 (DB4)
unnamed: U5.6 (A3), U7.12 (DB5)
unnamed: U5.7 (A4), U7.13 (DB6)
unnamed: U5.8 (A5), U7.14 (DB7)
unnamed: R26.1, U7.15 (A)
unnamed: RV1.2, U7.3 (VO)

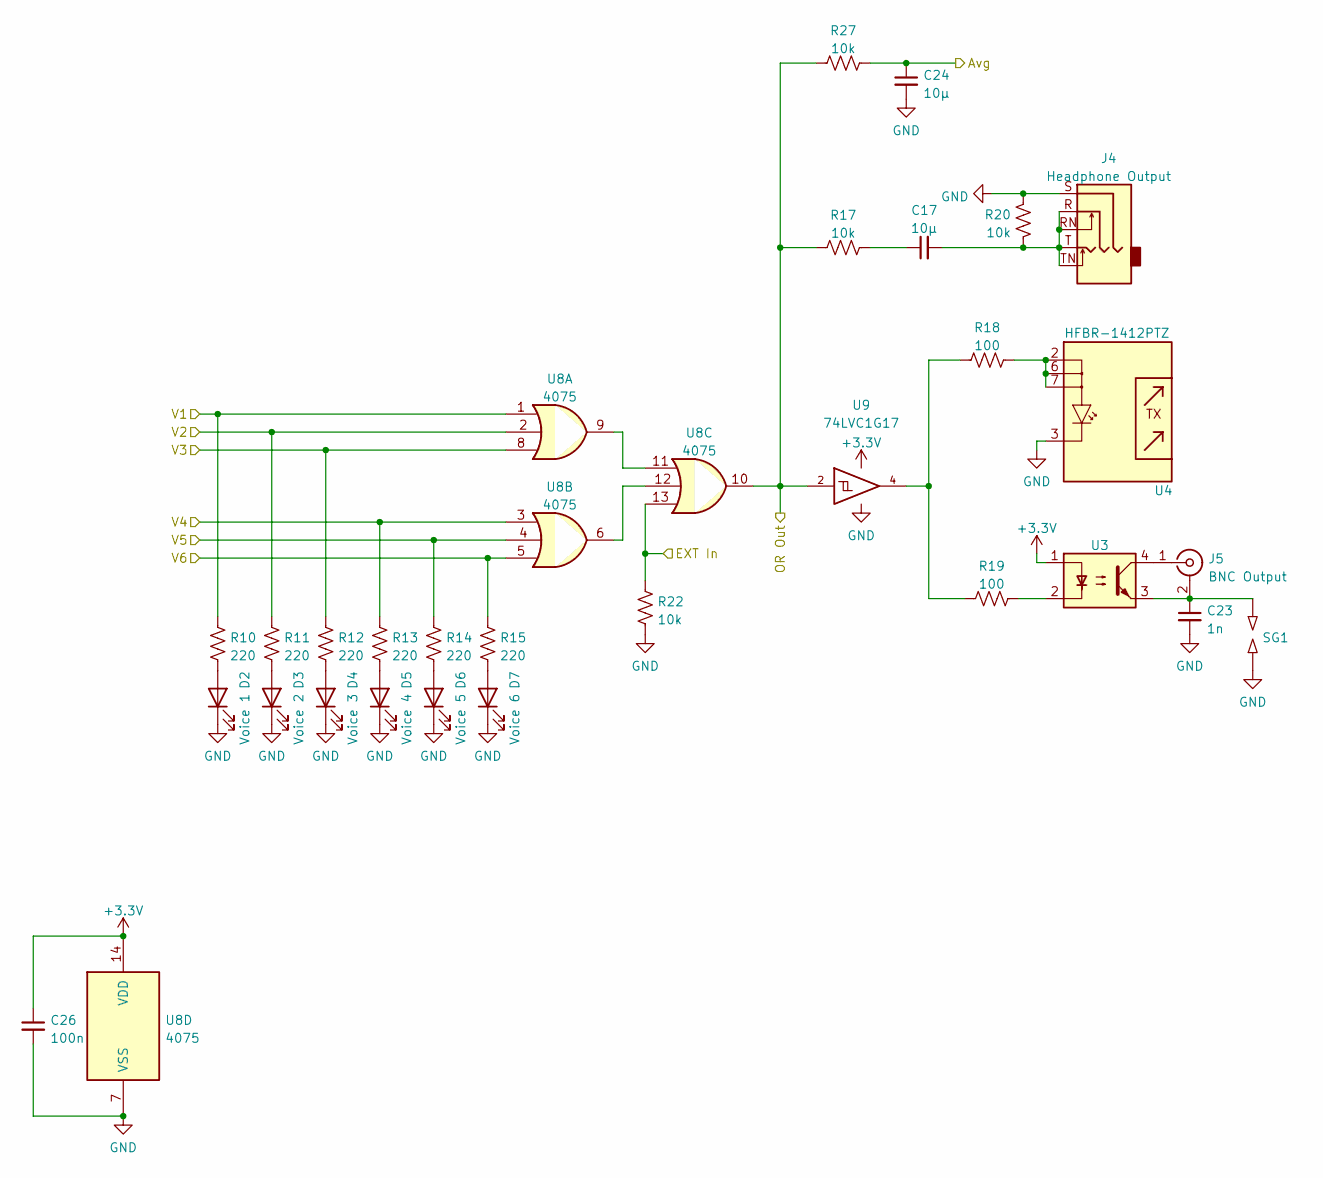
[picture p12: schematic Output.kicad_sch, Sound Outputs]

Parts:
C17, C24: 10µ; C_0805_2012Metric_Pad1.18x1.45mm_HandSolder
C23: 1n; C_Disc_D7.5mm_W5.0mm_P7.50mm
C26: 100n; C_0603_1608Metric_Pad1.08x0.95mm_HandSolder
D2: Voice 1; LED_D5.0mm
D3: Voice 2; LED_D5.0mm
D4: Voice 3; LED_D5.0mm
D5: Voice 4; LED_D5.0mm
D6: Voice 5; LED_D5.0mm
D7: Voice 6; LED_D5.0mm
J4: Headphone Output; Adam_Tech_ASJ-99H-X-HT-TR
J5: BNC Output; Adam_Tech_BNC_RF1-01K-D-00-50-BK-HDW
R10, R11, R12, R13, R14, R15: 220; R_0603_1608Metric_Pad0.98x0.95mm_HandSolder
R17, R20, R22, R27: 10k; R_0603_1608Metric_Pad0.98x0.95mm_HandSolder
R18, R19: 100; R_0603_1608Metric_Pad0.98x0.95mm_HandSolder
SG1: SparkGap; Spark_Gap
U3: SFH617A-1; DIP-4_W10.16mm
U4: HFBR-1412PTZ; Broadcom_HFBR-1412PTZ
U8: 4075; SOIC-14_3.9x8.7mm_P1.27mm
U9: 74LVC1G17; SOT-23-5

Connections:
+3.3V: C26.1, U3.1, U8.14 (VDD), U9.5 (VCC); also elsewhere on the board
/Avg: C24.1, R27.2; also elsewhere on the board
/Output/EXT In: R22.1, U8.13; also elsewhere on the board
/Output/OR Out: R17.1, R27.1, U8.10, U9.2; also elsewhere on the board
/TIOA0: R10.1, U8.1; also elsewhere on the board
/TIOA1: R11.1, U8.2; also elsewhere on the board
/TIOA2: R12.1, U8.8; also elsewhere on the board
/TIOA3: R13.1, U8.3; also elsewhere on the board
/TIOA4: R14.1, U8.4; also elsewhere on the board
/TIOA5: R15.1, U8.5; also elsewhere on the board
GND: C23.2, C24.2, C26.2, D2.1 (K), D3.1 (K), D4.1 (K), D5.1 (K), D6.1 (K), D7.1 (K), J4.S, R20.1, R22.2, SG1.1, U4.3, U8.7 (VSS), U9.3 (GND); also elsewhere on the board
unnamed: C17.1, R17.2
unnamed: C17.2, J4.R, J4.RN, J4.T, J4.TN, R20.2
unnamed: D2.2 (A), R10.2
unnamed: D3.2 (A), R11.2
unnamed: D4.2 (A), R12.2
unnamed: D5.2 (A), R13.2
unnamed: D6.2 (A), R14.2
unnamed: D7.2 (A), R15.2
unnamed: C23.1, J5.2 (Ext), SG1.2, U3.3
unnamed: J5.1 (In), U3.4
unnamed: R18.1, U4.2, U4.6, U4.7
unnamed: R18.2, R19.2, U9.4
unnamed: R19.1, U3.2
unnamed: U8.9, U8.11
unnamed: U8.6, U8.12

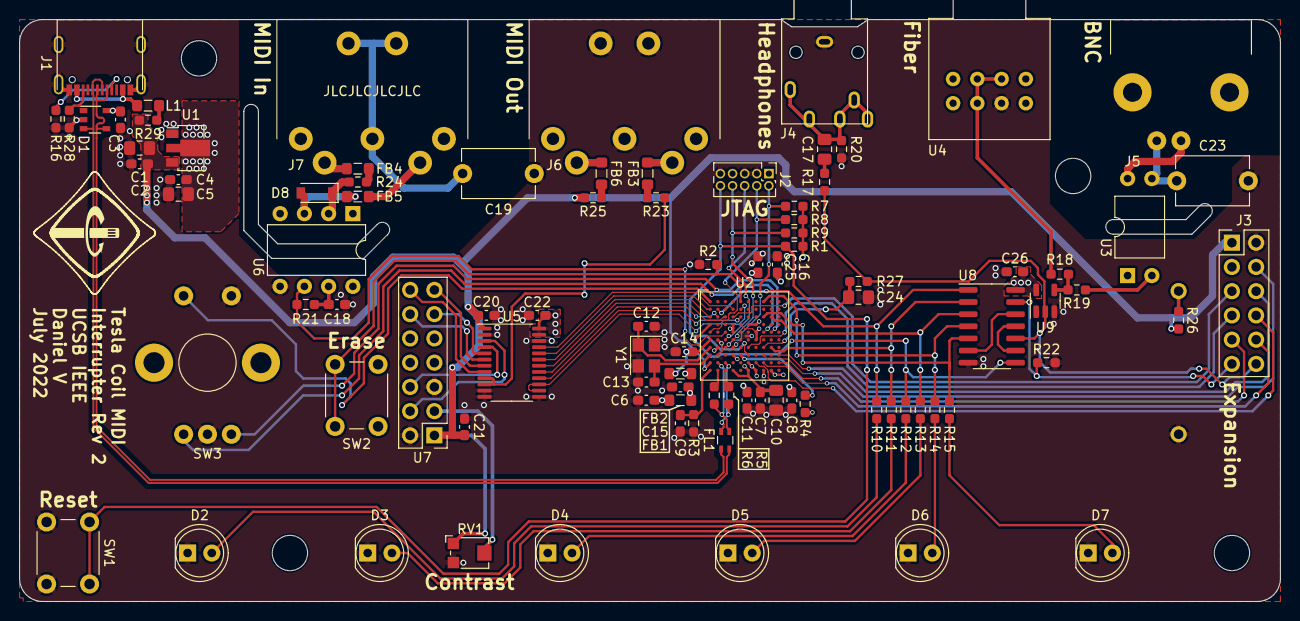
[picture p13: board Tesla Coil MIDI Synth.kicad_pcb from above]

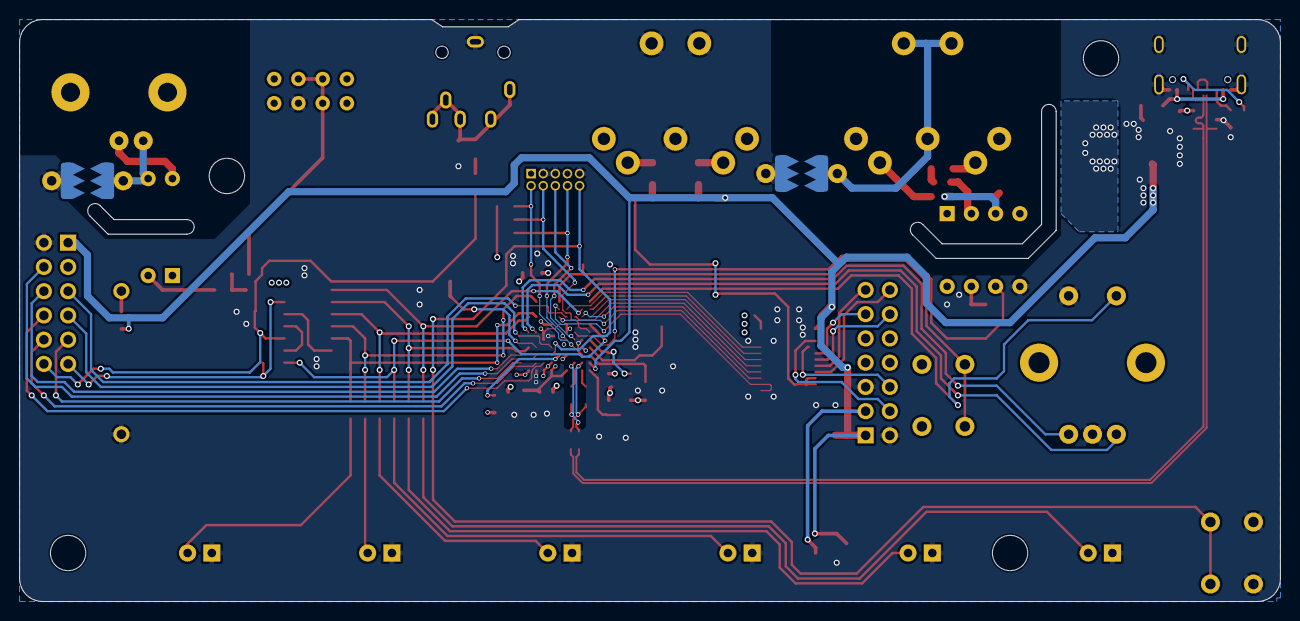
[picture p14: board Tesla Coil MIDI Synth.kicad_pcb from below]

Board: 4 copper layers, 132.1 x 61.0 mm, 94 parts (2 on the bottom side), 87 nets.

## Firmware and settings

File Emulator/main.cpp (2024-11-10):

#include <iostream>
#include <string>
#include <vector>
#include <list>
#include <utility>
#include <memory>

#include <libremidi/libremidi.hpp>
#include <portaudiocpp/PortAudioCpp.hxx>

#include "Coil.h"
#include "AudioEngine.h"
#include "LiquidCrystal.h"
#include "Version.h"

using namespace std;

// Ask user to choose something from a list
int choose(const char *message, vector<pair<string, int>> choices) {
	int choice;
	do {
		printf("%s\n", message);
		for(size_t x = 0; x < choices.size(); x++)
			printf("  [%lu] %s\n", x+1, choices[x].first.c_str());
		cin >> choice;
	} while(choice <= 0 || choice > (ssize_t)choices.size());
	return choices[choice-1].second;
}

int main(int argc, char **argv) {

	int ncoils = 1;

	// Parse args/print usage
	for(int x = 1; x < argc; x++) {
		string arg(argv[x]);
		if(arg == "--stereo") ncoils = 2;
		else {
			cout << "UCSB IEEE Tesla Coil Interrupter Emulator " VERSION
#ifndef RELEASE_BUILD
			"-dev"
#endif
			<< endl;
			cout << "Usage: " << argv[0] << " [--stereo]" << endl;
			cout << "\t--stereo: Emulate two coils, one on each audio channel. The right coil responds to MIDI channels 5+." << endl;
			return 1;
		}
	}

	// Initialize SDL
	LiquidCrystal::initialize();

	// Create Coil instances
	list<Coil> coils;
	if(ncoils == 1)
		coils.emplace_back("Tesla Coil Controller", 0, Coil::BOTH);
	else if(ncoils == 2) {
		coils.emplace_back("Tesla Coil Controller (Left)", 0, Coil::LEFT);
		coils.emplace_back("Tesla Coil Controller (Right)", 4, Coil::RIGHT);
	}

	// Create audio engine
	AudioEngine engine(coils);

	// Init portaudio
	portaudio::AutoSystem autoSys;
	portaudio::System &sys = portaudio::System::instance();

	// Select audio output device
	vector<pair<string, int>> deviceNames;
	auto filterDevices = [&](auto desiredParameters) {
		for(portaudio::System::DeviceIterator i = sys.devicesBegin(); i != sys.devicesEnd(); i++)
			// Make sure this device supports the desired parameters
			if(desiredParameters(*i).isSupported())
				deviceNames.emplace_back(i->name(), i->index());
	};

	filterDevices(AudioEngine::desiredOutputParameters);
	portaudio::Device &outputDevice = sys.deviceByIndex(choose("Choose audio output device", deviceNames));
	portaudio::CFunCallbackStream outputStream(AudioEngine::desiredOutputParameters(outputDevice), &AudioEngine::outputCallback, &engine);

	deviceNames.clear();
	deviceNames.emplace_back("None", -1);
	filterDevices(AudioEngine::desiredInputParameters);
	const int inputDeviceInd = choose("Choose audio input device", deviceNames);
	unique_ptr<portaudio::CFunCallbackStream> inputStream;
	if(inputDeviceInd >= 0) {
		portaudio::Device &inputDevice = sys.deviceByIndex(inputDeviceInd);
		inputStream.reset(new portaudio::CFunCallbackStream(AudioEngine::desiredInputParameters(inputDevice), &AudioEngine::inputCallback, &engine));
	}

	// Select MIDI input device
	libremidi::midi_in midi;
	deviceNames.clear();
	deviceNames.emplace_back("None", -1);
	for(unsigned int x = 0; x < midi.get_port_count(); x++)
		deviceNames.emplace_back(midi.get_port_name(x), x);

	const int chosenMidiDevice = choose("Choose MIDI input device", deviceNames);
	if(chosenMidiDevice >= 0) {
		midi.open_port(chosenMidiDevice);

		midi.set_callback([&](const libremidi::message& message) {
			unsigned char pass[3] = {0};
			switch(message.size()) {
				case 0:
					return;
				default:
				case 3:
					pass[2] = message[2];
				case 2:
					pass[1] = message[1];
				case 1:
					pass[0] = message[0];
					break;
			}
			for(auto &coil:coils)
				coil.handleMIDI(pass);
		});
	}

	outputStream.start();
	if(inputStream)
		inputStream->start();

	// Run until user quits
	while(LiquidCrystal::pollSDL())
		for(auto &coil:coils) {
			coil.lcd.update();
			coil.knob.update();
		}

	outputStream.stop();
	if(inputStream)
		inputStream->stop();

	coils.clear();

	LiquidCrystal::destroy();

	return 0;
}

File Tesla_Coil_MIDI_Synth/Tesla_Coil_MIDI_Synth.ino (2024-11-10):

/* 
 * Standard MIDI things
    * Pitch bend
    * Aftertouch
 * Effects
    * Tremolo (volume) (rate = 102, depth = 92, delay = 103)
    * Vibrato (pitch) (rate = 76, depth = 77, delay = 78)
    * ADSR (116, 117, 118, 119)
    * Arpeggio rate (14)
 * Channels
    * 1: Clean (no effects)
    * 2: Effects
    * 3: Arpeggio and effects
    * 4: Drums: kick (36/C2), snare (40/E2), clap (39/D#2), tom (48/C3), and hi-hat (42/F#2)
 */

#include "Voice.h"
#include "Synth.h"
#include "LCD.h"
#include "MIDI.h"
#include "Audio.h"
#include "Knob.h"
#include "Connected.h"

extern Voices    voices;
extern Synth     synth;
extern LCD       lcd;
extern MIDI      midi;
extern Audio     audio;
extern Knob      knob;
extern Connected conn;

Voices    voices;
Synth     synth (voices,             midi       );
LCD       lcd   (        synth,      midi, audio);
MIDI      midi  (voices, synth, lcd             );
Audio     audio;
Knob      knob  (        synth, lcd, midi, audio);
Connected conn  (        synth,            audio);

void setup() {
  midi.init();
  voices.init();
  audio.init();
  lcd.init();
  knob.init();
}

void loop() {
  midi.process();
  audio.process();
  lcd.update();
  knob.update();
}

// Must be in main file to override default handler
void PWM_Handler() {
  audio.setDMABuffer();
}

extern "C" {
int sysTickHook() { // Runs at 1kHz
  conn.checkConnected();
  synth.update();
  return 0;
}
}

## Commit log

2022-05-04 reworked arpeggio code to allow it to carry through ADSR release
    so many timer race condition bugs
    for loops are hard
    why
    why
    why
    why
    why
    why
    [Tesla_Coil_MIDI_Synth.ino]
2022-05-04 actually DO need to update the timers even if the stuff didn't change
    [Tesla_Coil_MIDI_Synth.ino]
2022-05-04 improved drum samples
2022-05-20 made MIDI velocity optionally control absolute pulse width or relative to frequency
2022-08-08 designed PCB
    [BOM.csv, LCD.kicad_sch, MIDI.kicad_sch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]
2022-08-16 interactive BOM
2022-08-17 refactored code and added UI for new PCB
2022-08-19 fix board thickness
    [Tesla Coil MIDI Synth.kicad_pcb]
2022-08-19 notes on PCB
2022-08-19 note on erase button
2022-08-19 update BOM
    [BOM.csv]
2022-08-19 add case files
    [Bottom No Fiber Optic.stl, Bottom.stl, Button Pusher.stl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]
2022-08-19 fix MIDI note velocity on effects channels
2022-12-22 fixed PCB
    * Added 5.1k resistors to CC lines on USB-C port
    * Replaced diode OR thing and MOSFET with too low of a threshold voltage with a real OR gate and buffer
    * Fixed polarity of BNC output
    * Made headphone output not murderously loud and asymmetric
    * Added direct in/out to expansion pins
    * Reduced impedance into ADC for average volume level sensing
    * Increased MIDI input pullup resistance
    * Made thermal spokes to copper planes thinner
    [BOM.csv, MIDI.kicad_sch, Output.kicad_sch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]
2023-01-16 made pitch bend and vibrato more musical
    should relate to powers of 2 instead of being linear
    [MIDI.h]
2023-04-03 change pitch bend range to 2 semitones
2023-04-13 improved power line filtering
    [BOM.csv, LCD.kicad_sch, MIDI.kicad_sch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]
2023-04-29 changed via size to 0.3mm drill
    [Tesla Coil MIDI Synth-B_Cu.gbr, Tesla Coil MIDI Synth-B_Mask.gbr, Tesla Coil MIDI Synth-B_Silkscreen.gbr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]
2023-05-20 adjust value to make LCD happy
    [BOM.csv, Tesla Coil MIDI Synth.kicad_pcb, Tesla Coil MIDI Synth.kicad_sch]
2023-05-21 make case curvy and update PCB model
    [Bottom No Fiber Optic.stl, Bottom.stl, Top.stl]
2023-07-22 make timer behavior more realistic
    also fixes pitch bend and vibrato weirdness
2024-02-23 add USB disconnect failsafe
    [MIDI.cpp, MIDI.h, Tesla_Coil_MIDI_Synth.ino]
2024-04-23 switch to `#pragma once`
2024-04-28 mention required Arduino libraries
2024-04-28 improve emulator audio realism
    convolve output with sampled IR of Tesla Coil + reverb
2024-05-04 run audio processing in callback
    separate generator thread was not running with high enough priority and was causing dropouts
2024-05-04 experimental USB audio support
    requires hardware modification to rev <= 2 boards to connect PWM output pin
2024-09-30 move DMA ISR
2024-11-11 move parameter updates out of interrupt handler
    to solve crash due to interrupt overload
    [Knob.cpp]
2024-11-12 handle channel aftertouch messages
    corrected interpretation of length of messages on physical port
    also added physical MIDI IN -> USB passthrough
    [MIDI.cpp, MIDI.h]
2024-11-12 fix encoder bug
